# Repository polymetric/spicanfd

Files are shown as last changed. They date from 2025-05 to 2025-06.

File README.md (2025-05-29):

# spicanfd
Add a CAN-FD interface to a microcontroller through SPI. Uses the MCP2517FD chip + ATA6561 transceiver.

Based on [Longan Labs' CAN FD Shield](https://github.com/Longan-Labs/Longan_Labs_CAN_FD_Eagle/) for the Arduino Uno. It's basically a breakout board form of that. Their shield is nicer to use but this board is a lot cheaper to fab since it's smaller and has less components.

For usage, please refer to the [MCP2517FD datasheet](https://ww1.microchip.com/downloads/en/DeviceDoc/MCP2517FD-External-CAN-FD-Controller-with-SPI-Interface-20005688B.pdf) and the [acan2517FD](https://github.com/pierremolinaro/acan2517FD) Arduino library.




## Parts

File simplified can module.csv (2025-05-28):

Reference | Value | Footprint | Datasheet | Qty | DNP | Exclude from BOM | Exclude from Board
C1,C2 | 22pF | Capacitor_SMD:C_0603_1608Metric |  | 2
C3,C4 | 100nF | Capacitor_SMD:C_0603_1608Metric |  | 2
INT1,RX1,TX1 | RED | LED_SMD:LED_0603_1608Metric | ~ | 3
J1 | Conn_01x07_Pin | Connector_PinHeader_2.54mm:PinHeader_1x07_P2.54mm_Vertical | ~ | 1
J2 | SCREW-TERMINAL-2P'5.08' | Connector_PinHeader_2.54mm:PinHeader_1x03_P2.54mm_Vertical | ~ | 1
PWR1 | GREEN | LED_SMD:LED_0603_1608Metric | ~ | 1
R1 | 120R | Resistor_SMD:R_0603_1608Metric |  | 1
R2,R3,R4,R5 | 1k | Resistor_SMD:R_0603_1608Metric |  | 4
U1 | MCP2517FD | Package_SO:SOIC-14_3.9x8.7mm_P1.27mm |  | 1
U2 | MCP2542 | Package_SO:SOIC-8_3.9x4.9mm_P1.27mm |  | 1
X1 | 20MHz | Crystal:Crystal_SMD_HC49-SD |  | 1

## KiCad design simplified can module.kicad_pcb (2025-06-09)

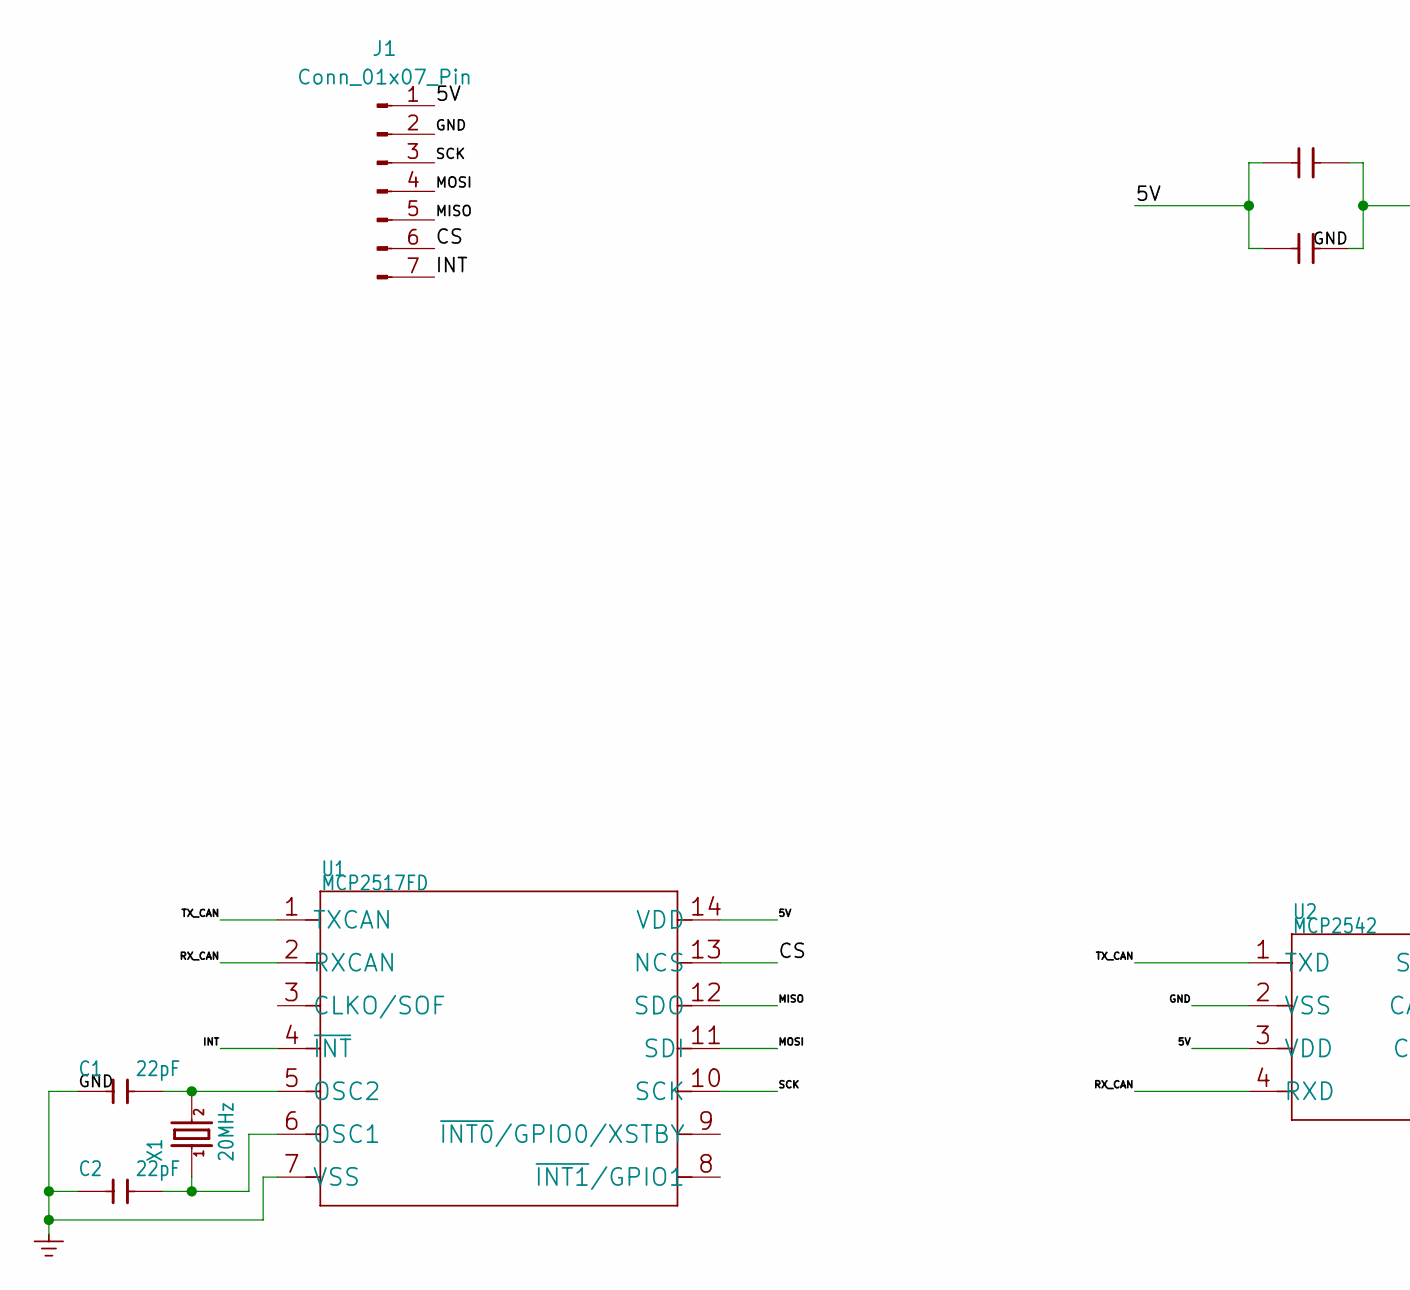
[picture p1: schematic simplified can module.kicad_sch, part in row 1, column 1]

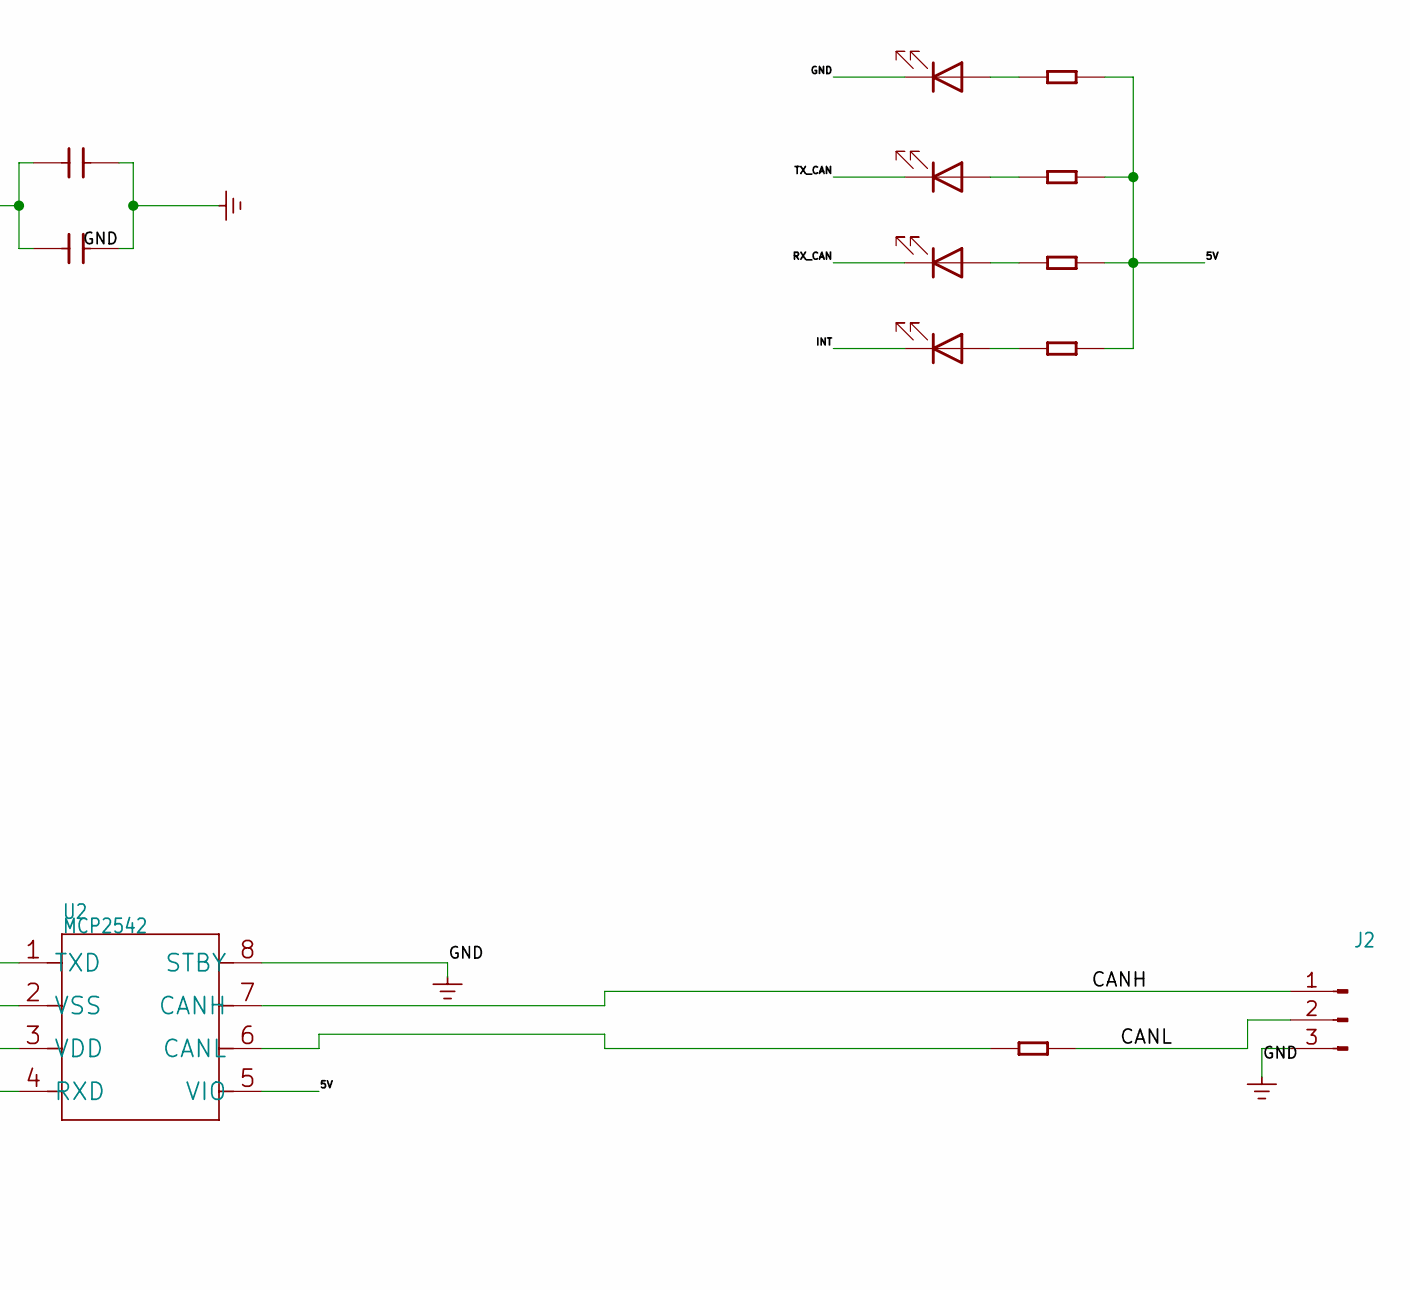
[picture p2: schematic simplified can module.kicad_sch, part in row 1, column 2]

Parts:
C1, C2: 22pF; C_0603_1608Metric
C3, C4: 100nF; C_0603_1608Metric
INT1: RED; LED_0603_1608Metric
J1: Conn_01x07_Pin; PinHeader_1x07_P2.54mm_Vertical
J2: SCREW-TERMINAL-2P'5.08'; PinHeader_1x03_P2.54mm_Vertical
PWR1: GREEN; LED_0603_1608Metric
R1: 120R; R_0603_1608Metric
R2, R3, R4, R5: 1k; R_0603_1608Metric
RX1: RED; LED_0603_1608Metric
TX1: RED; LED_0603_1608Metric
U1: MCP2517FD; SOIC-14_3.9x8.7mm_P1.27mm
U2: MCP2542; SOIC-8_3.9x4.9mm_P1.27mm
X1: 20MHz; Crystal_SMD_HC49-SD

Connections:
/5V: C3.1, C4.1, J1.1, R2.2, R3.2, R4.2, R5.2, U1.14 (VDD), U2.3 (VDD), U2.5 (VIO)
/CANH: J2.1, U2.7 (CANH)
/CANL: J2.2, R1.2
/CS: J1.6, U1.13 (NCS)
/INT: INT1.1 (K), J1.7, U1.4 (~INT)
/MISO: J1.5, U1.12 (SDO)
/MOSI: J1.4, U1.11 (SDI)
/RX_CAN: RX1.1 (K), U1.2 (RXCAN), U2.4 (RXD)
/SCK: J1.3, U1.10 (SCK)
/TX_CAN: TX1.1 (K), U1.1 (TXCAN), U2.1 (TXD)
GND_POWER: C1.1, C2.1, C3.2, C4.2, J1.2, J2.3, PWR1.1 (K), U1.7 (VSS), U2.2 (VSS), U2.8 (STBY)
unnamed: INT1.2 (A), R5.1
unnamed: PWR1.2 (A), R2.1
unnamed: R4.1, RX1.2 (A)
unnamed: R3.1, TX1.2 (A)
unnamed: C2.2, U1.6 (OSC1), X1.1
unnamed: C1.2, U1.5 (OSC2), X1.2
unnamed: R1.1, U2.6 (CANL)

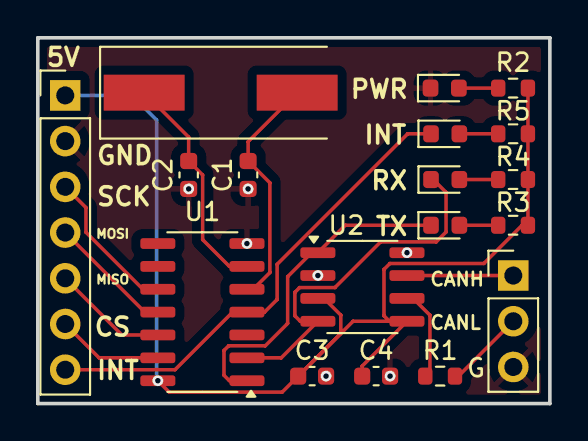
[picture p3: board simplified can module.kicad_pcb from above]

Board: 2 copper layers, 28.4 x 20.3 mm, 18 parts (0 on the bottom side), 18 nets.

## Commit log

2025-05-28 move fab labels and add bom
    [simplified can module.csv, simplified can module.kicad_pcb, simplified can module.kicad_sch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]
2025-05-28 add kicad 3d image
2025-05-29 add CAN pin labels
    also:
    - reduced thermal relief spoke size to help soldering
    - changed solder mask color to purple in 3d renderer
    [simplified can module.kicad_pcb]
2025-05-29 update CAN header labels
    [simplified can module.kicad_pcb]
2025-06-09 add copyright and version info
    [simplified can module.kicad_pcb]

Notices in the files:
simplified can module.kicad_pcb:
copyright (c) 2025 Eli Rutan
